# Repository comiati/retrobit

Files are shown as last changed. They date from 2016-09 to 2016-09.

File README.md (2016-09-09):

# RetroBit Game Console

This is a mix of retro game console with new technologies.

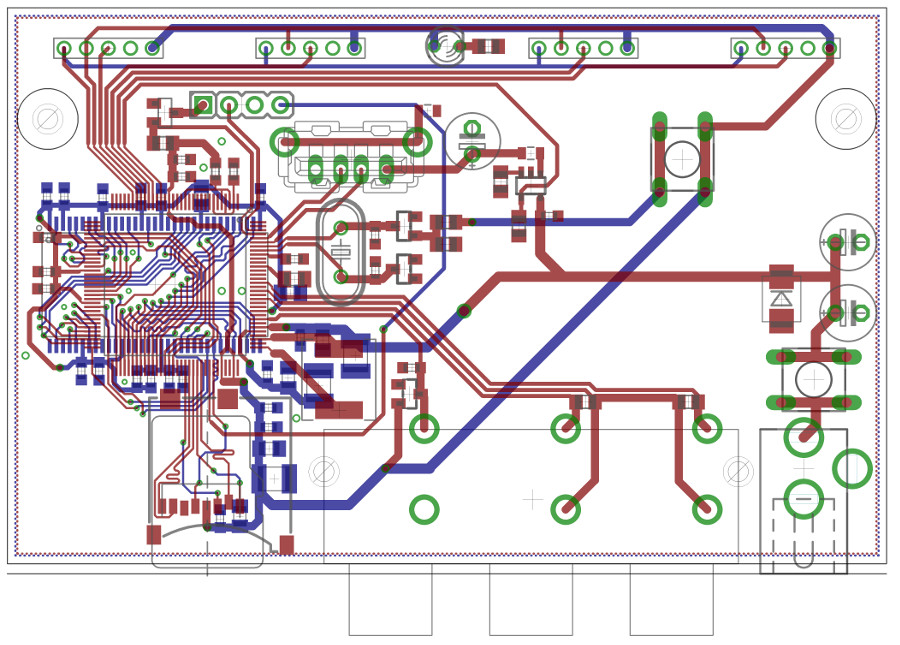
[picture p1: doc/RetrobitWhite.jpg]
RetroBit Board


## Hardware

This is ARM9 processor running at 454Mhz with enough power to run linux and still in handsolder friendly TQFP package, which allow hobby DIY approach. RetroBit is even on 2 layer PCB and running at full speed.

######

- i.MX233 128-QFP Processor ARM926EJ-S runs up to 454MHz
- Memory 64MB DDR SDRAM (32Mx16)
- One USB host.
- Four input game pad controls.
- One degub UART.
- Composite video output.
- Stereo sound output.
- Micro SD Card.
- Power suply with power button and Led.
- Reset button.

## Software

ArchLinux package for the moment is with most advanced Kernel and enabled features so this is our choice for the moment to build examples.

This hardware is based on OLinuxXino of www.olimex.com
https://github.com/OLIMEX/OLINUXINO/tree/master/SOFTWARE/iMX233

For more informations send email to: fabianotraple@gmail.com

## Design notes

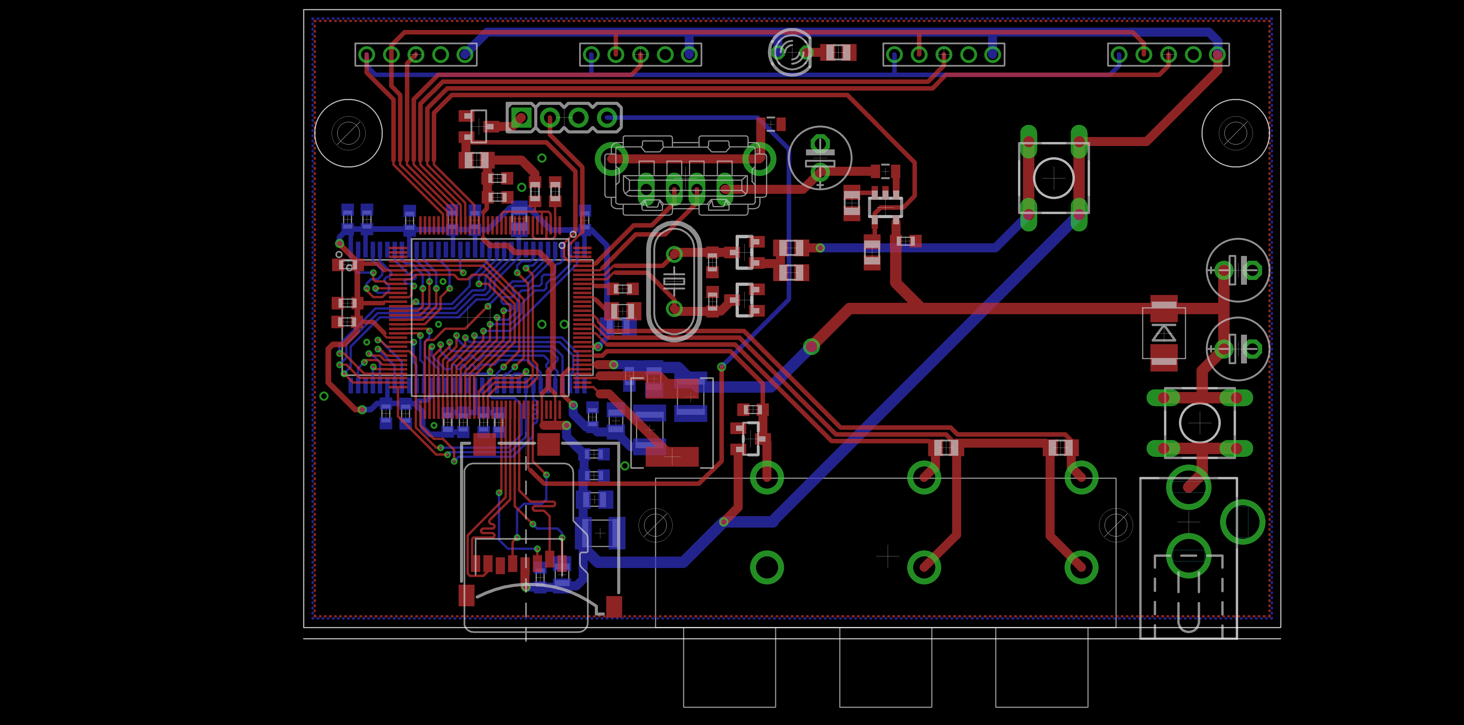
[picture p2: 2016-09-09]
doc/RetroBit.png

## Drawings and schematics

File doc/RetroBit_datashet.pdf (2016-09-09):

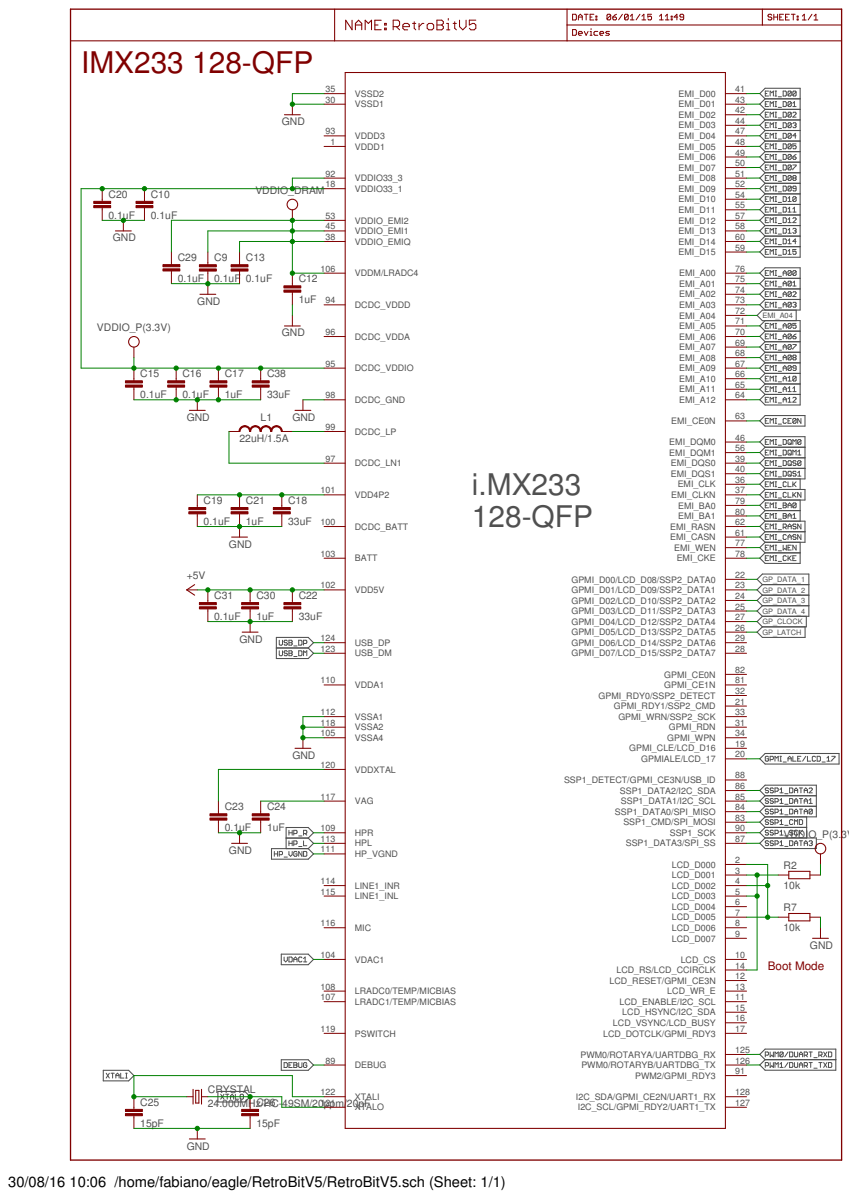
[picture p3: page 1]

4 | 10k R7

30/08/16 10:06 /home/fabiano/eagle/RetroBitV5/RetroBitV5.sch (Sheet: 1/1)

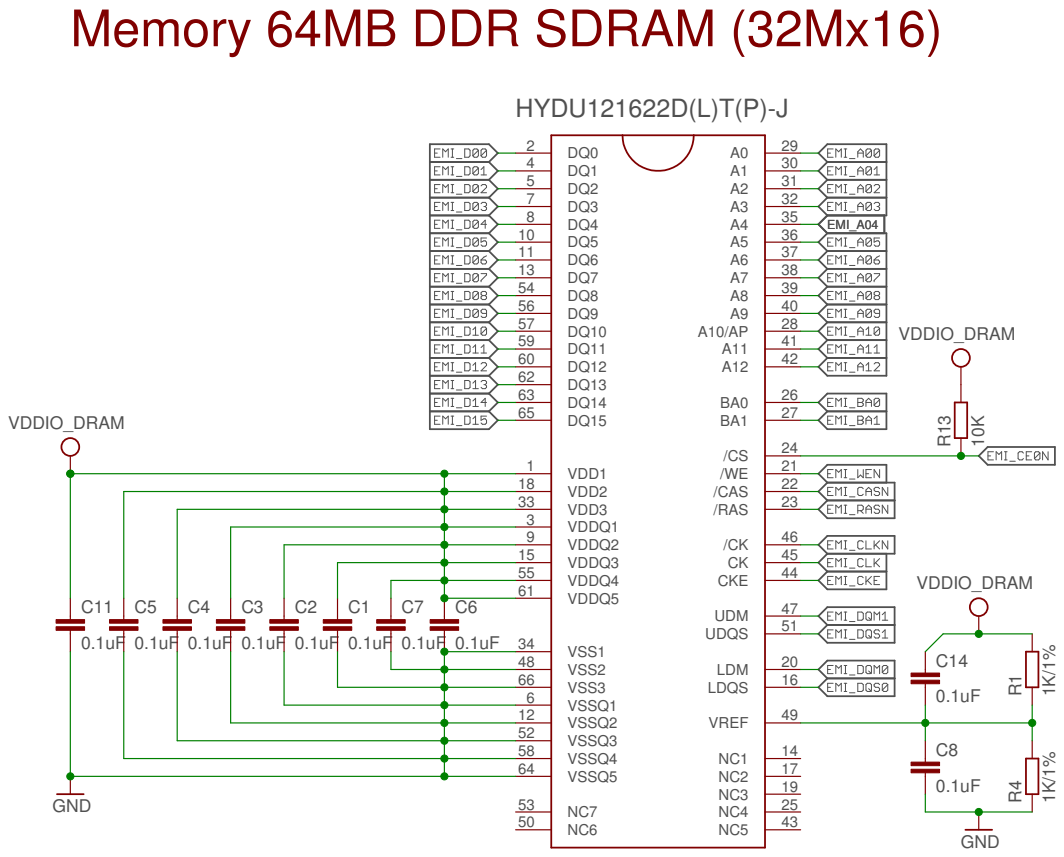
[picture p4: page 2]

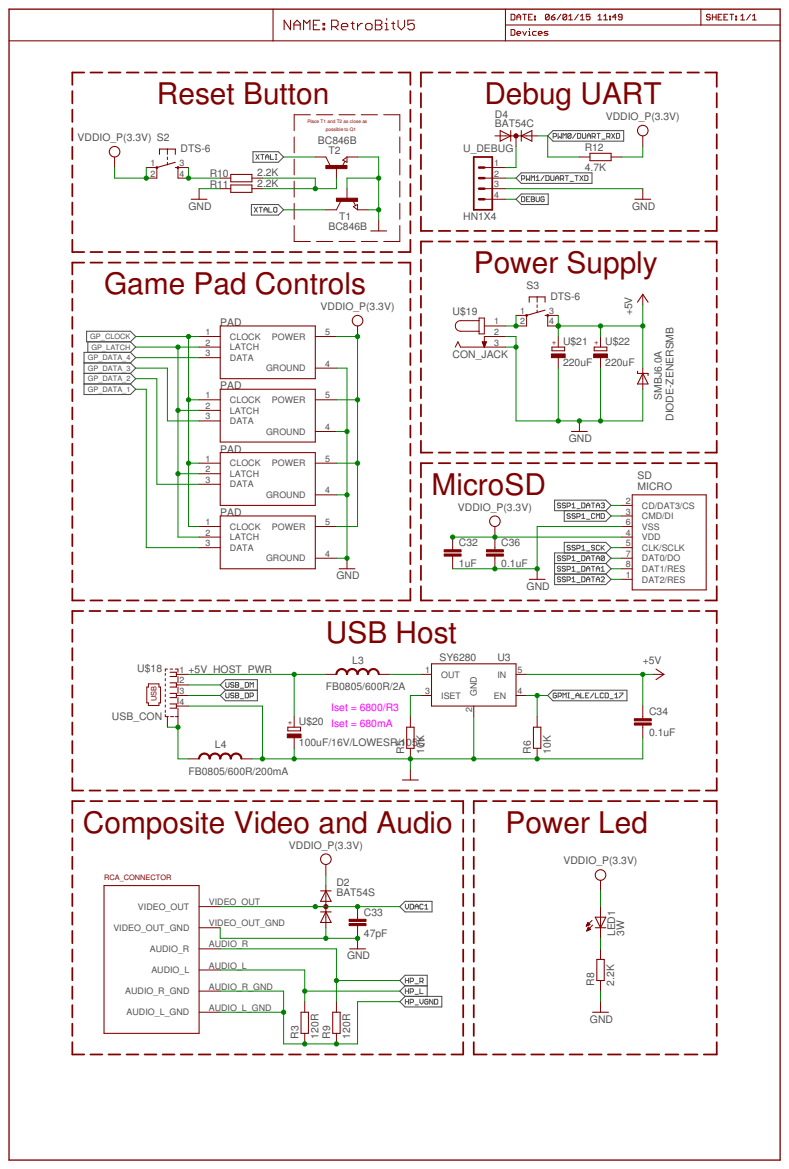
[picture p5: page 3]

Place T1 and T2 as close as possible to Q1 Reset Button

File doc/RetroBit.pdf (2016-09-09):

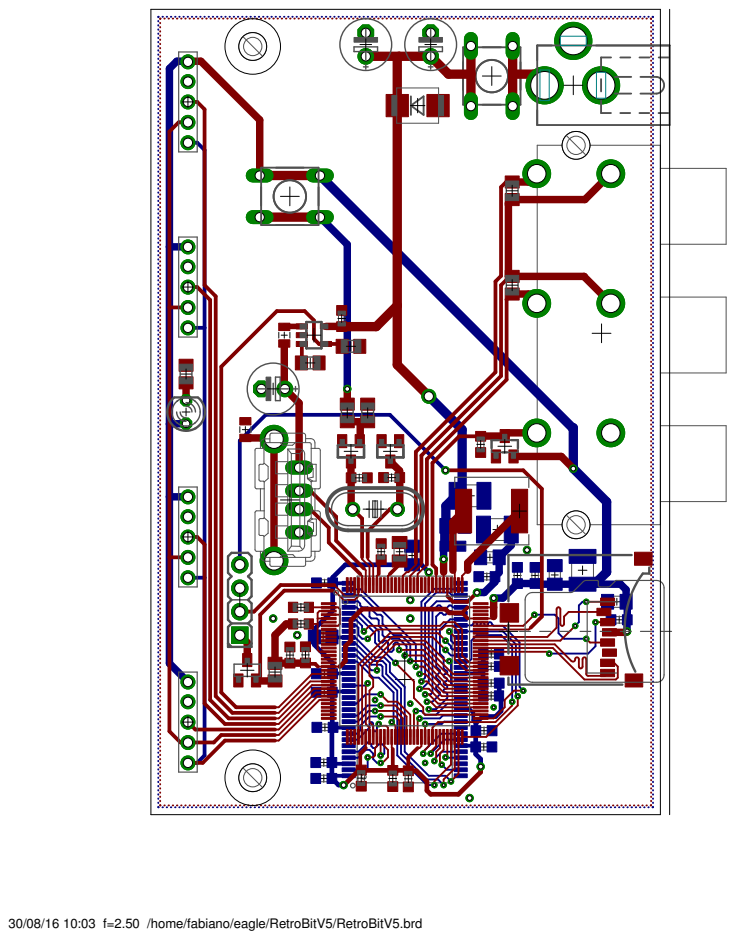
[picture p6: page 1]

30/08/16 10:03 f=2.50 /home/fabiano/eagle/RetroBitV5/RetroBitV5.brd

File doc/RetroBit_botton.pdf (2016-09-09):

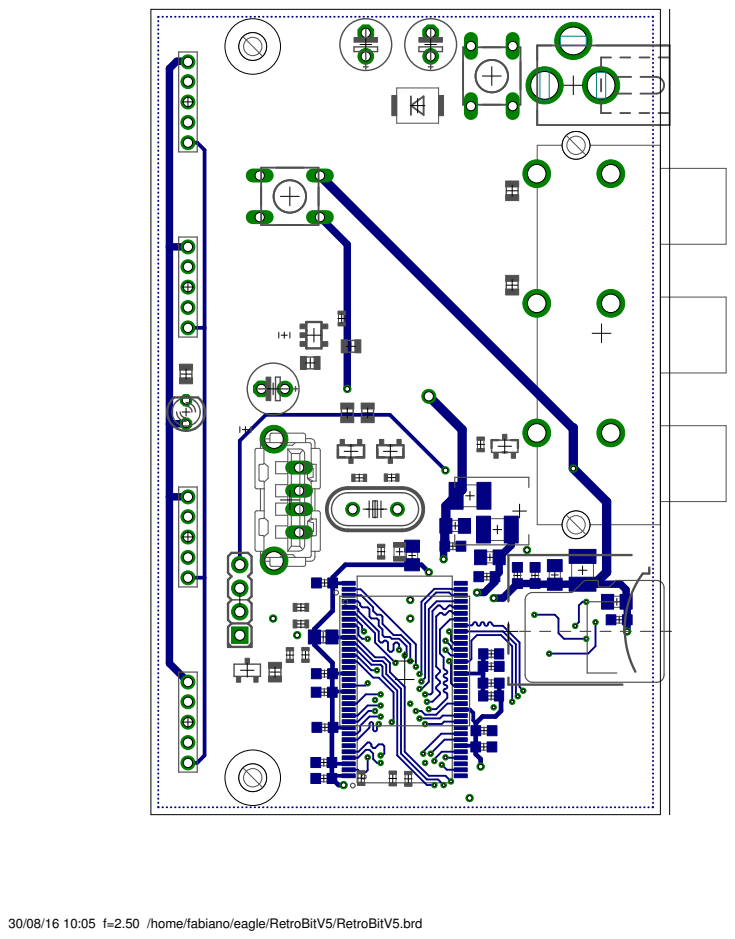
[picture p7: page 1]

30/08/16 10:05 f=2.50 /home/fabiano/eagle/RetroBitV5/RetroBitV5.brd

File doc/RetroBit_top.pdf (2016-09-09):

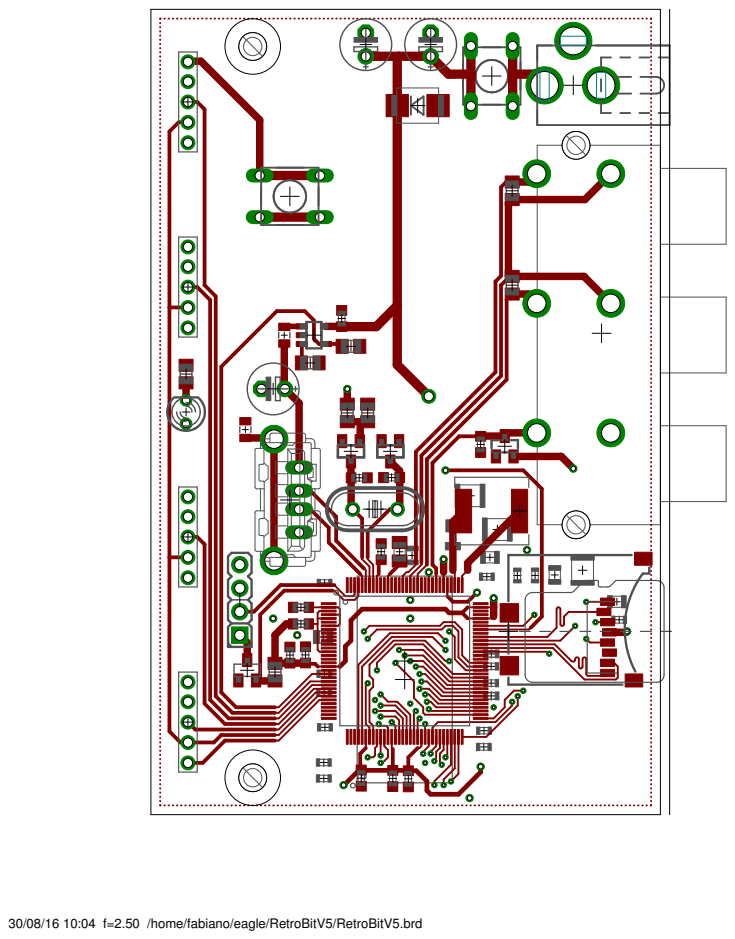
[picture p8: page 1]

30/08/16 10:04 f=2.50 /home/fabiano/eagle/RetroBitV5/RetroBitV5.brd

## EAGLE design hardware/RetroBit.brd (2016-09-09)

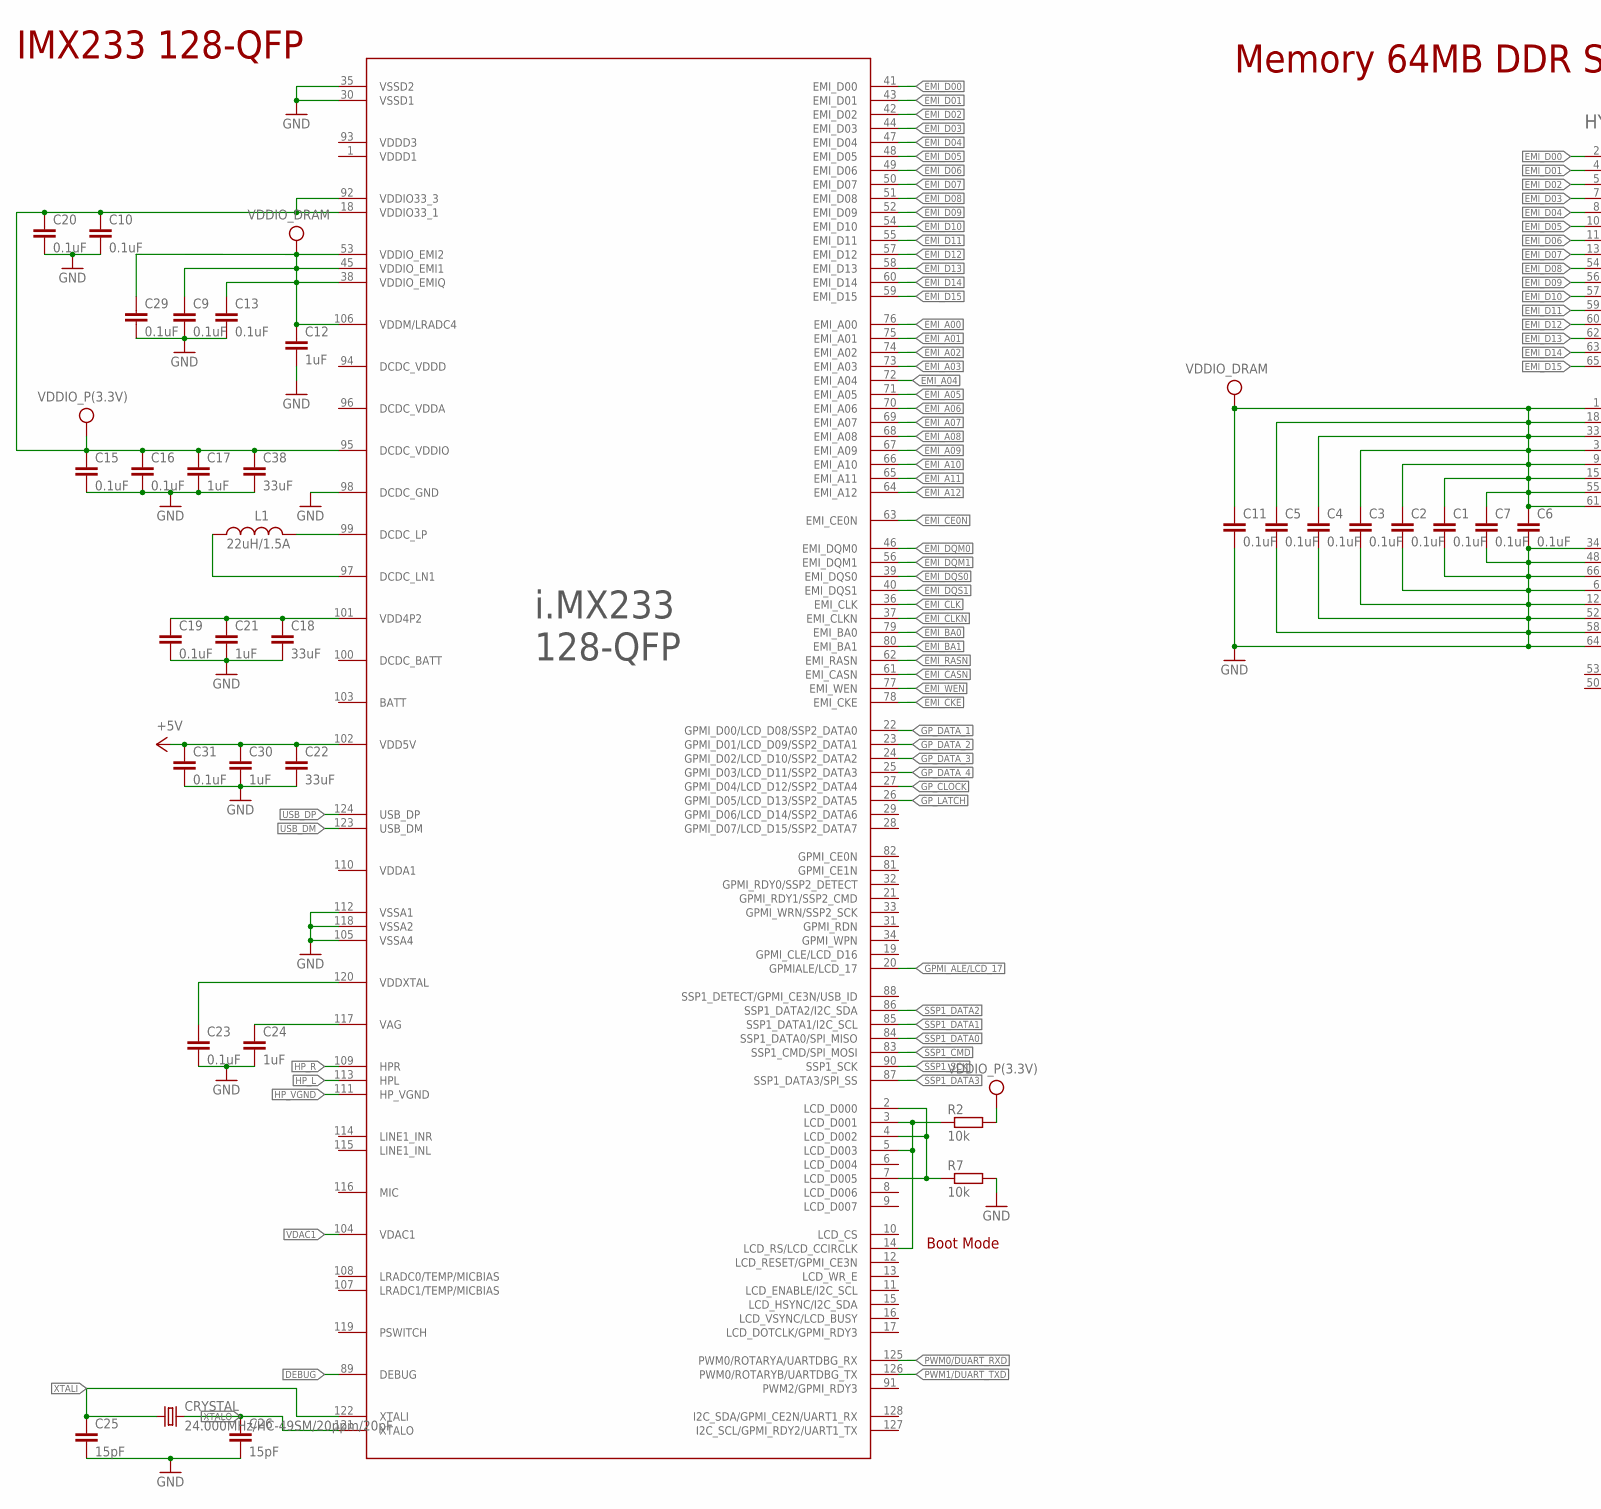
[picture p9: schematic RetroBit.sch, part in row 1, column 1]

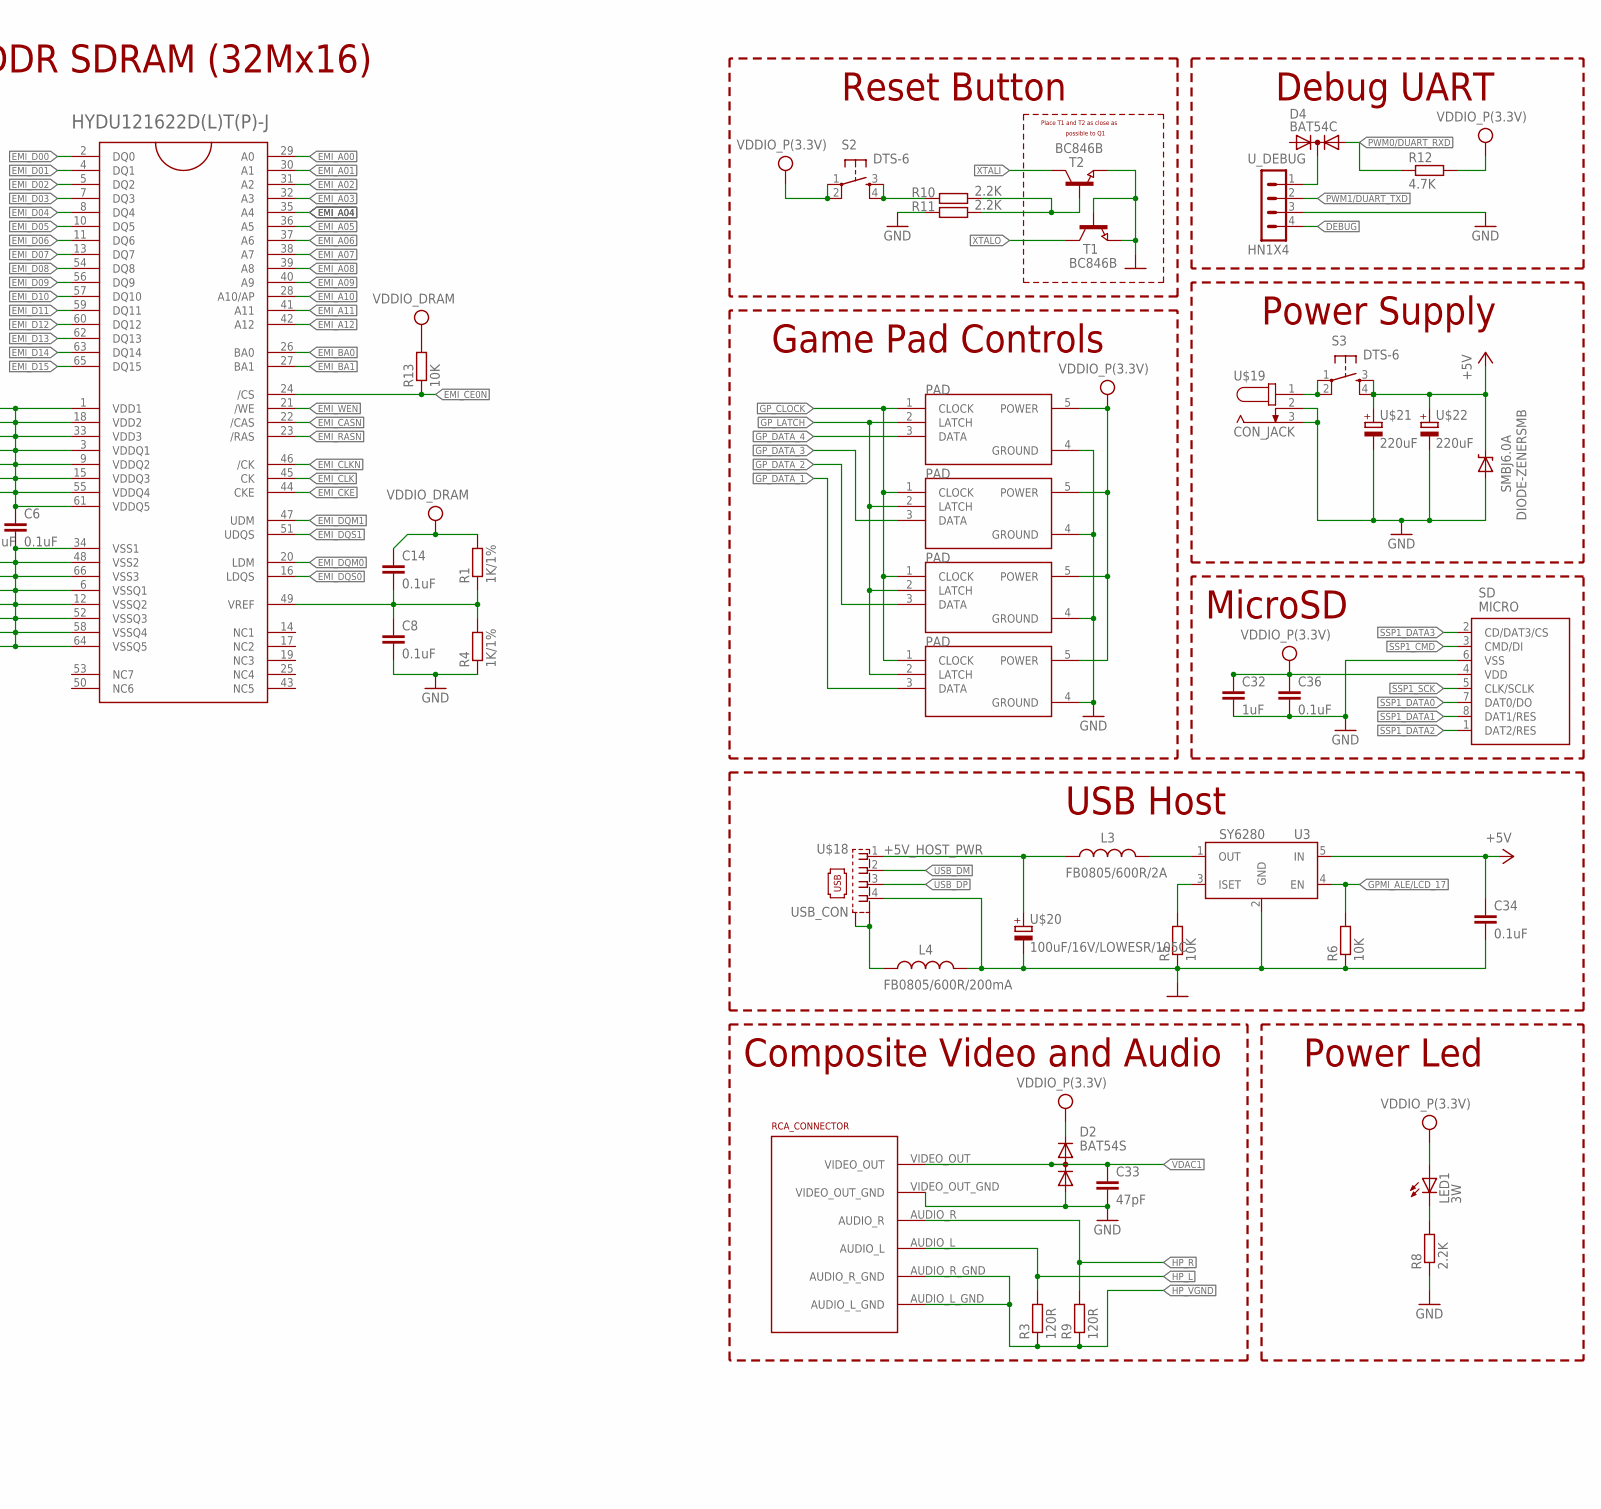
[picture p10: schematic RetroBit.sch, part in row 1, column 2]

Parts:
C1, C2, C3, C4, C5, C6, C7, C8, C9, C10, C11, C13, C14, C15, C16, C19, C20, C23, C29, C31, C34, C36: 0.1uF; C0603K
C12, C17, C21, C24, C30, C32: 1uF; C0805K
C18, C22, C38: 33uF; C1210K
C25, C26: 15pF; C0603K
C33: 47pF; C0603K
CRYSTAL: 24.000MHz/HC-49SM/20ppm/20pF; HC49U-V
D2: BAT54S; SOT23C(BAT54S)
D4: BAT54C; SOT23C
IC1: MCIMX233CAG4C
L1: 22uH/1.5A; CR75
L3: FB0805/600R/2A; 0805
L4: FB0805/600R/200mA; 0805
LED1: 3W; LED3MM
R1, R4: 1K/1%; R0603
R2, R7: 10k; R0603
R3, R9: 120R; R0805
R5, R6, R13: 10K; R0805
R8, R10, R11: 2.2K; R0805
R12: 4.7K; R0805
RCA_CONNECTOR: RCA_CONNECTOR
S2, S3: DTS-6
SD: MICRO; TFR-MEM-CON
SMBJ6.0A: DIODE-ZENERSMB; SMB-DIODE
T1, T2: BC846B; SOT23
U3: SY6280; SOT23-5
U$1: HY5DU121622D; HYDU121622D(L)T(P)-J
U$3, U$8, U$9, U$14: GAME_PAD
U$18: USB_CON
U$19: CON_JACK
U$20: 100uF/16V/LOWESR/105C; CPOL-EVE-2.5,6-3
U$21, U$22: 220uF; CPOL-EVE-2.5,6-3
U_DEBUG: HN1X4

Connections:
+5V: C22.1, C30.1, C31.1, C34.1, IC1.102 (VDD5V), S3.3, S3.4, SMBJ6.0A.C, U3.5 (IN), U$21.+, U$22.+
+5V_HOST_PWR: L3.1, U$18.1, U$20.+
DEBUG: IC1.89 (DEBUG), U_DEBUG.4
EMI_A00: IC1.76 (EMI_A00), U$1.29 (A0)
EMI_A01: IC1.75 (EMI_A01), U$1.30 (A1)
EMI_A02: IC1.74 (EMI_A02), U$1.31 (A2)
EMI_A03: IC1.73 (EMI_A03), U$1.32 (A3)
EMI_A04: IC1.72 (EMI_A04), U$1.35 (A4)
EMI_A05: IC1.71 (EMI_A05), U$1.36 (A5)
EMI_A06: IC1.70 (EMI_A06), U$1.37 (A6)
EMI_A07: IC1.69 (EMI_A07), U$1.38 (A7)
EMI_A08: IC1.68 (EMI_A08), U$1.39 (A8)
EMI_A09: IC1.67 (EMI_A09), U$1.40 (A9)
EMI_A10: IC1.66 (EMI_A10), U$1.28 (A10/AP)
EMI_A11: IC1.65 (EMI_A11), U$1.41 (A11)
EMI_A12: IC1.64 (EMI_A12), U$1.42 (A12)
EMI_BA0: IC1.79 (EMI_BA0), U$1.26 (BA0)
EMI_BA1: IC1.80 (EMI_BA1), U$1.27 (BA1)
EMI_CASN: IC1.61 (EMI_CASN), U$1.22 (/CAS)
EMI_CE0N: IC1.63 (EMI_CE0N), R13.1, U$1.24 (/CS)
EMI_CKE: IC1.78 (EMI_CKE), U$1.44 (CKE)
EMI_CLK: IC1.36 (EMI_CLK), U$1.45 (CK)
EMI_CLKN: IC1.37 (EMI_CLKN), U$1.46 (/CK)
EMI_D00: IC1.41 (EMI_D00), U$1.2 (DQ0)
EMI_D01: IC1.43 (EMI_D01), U$1.4 (DQ1)
EMI_D02: IC1.42 (EMI_D02), U$1.5 (DQ2)
EMI_D03: IC1.44 (EMI_D03), U$1.7 (DQ3)
EMI_D04: IC1.47 (EMI_D04), U$1.8 (DQ4)
EMI_D05: IC1.48 (EMI_D05), U$1.10 (DQ5)
EMI_D06: IC1.49 (EMI_D06), U$1.11 (DQ6)
EMI_D07: IC1.50 (EMI_D07), U$1.13 (DQ7)
EMI_D08: IC1.51 (EMI_D08), U$1.54 (DQ8)
EMI_D09: IC1.52 (EMI_D09), U$1.56 (DQ9)
EMI_D10: IC1.54 (EMI_D10), U$1.57 (DQ10)
EMI_D11: IC1.55 (EMI_D11), U$1.59 (DQ11)
EMI_D12: IC1.57 (EMI_D12), U$1.60 (DQ12)
EMI_D13: IC1.58 (EMI_D13), U$1.62 (DQ13)
EMI_D14: IC1.60 (EMI_D14), U$1.63 (DQ14)
EMI_D15: IC1.59 (EMI_D15), U$1.65 (DQ15)
EMI_DQM0: IC1.46 (EMI_DQM0), U$1.20 (LDM)
EMI_DQM1: IC1.56 (EMI_DQM1), U$1.47 (UDM)
EMI_DQS0: IC1.39 (EMI_DQS0), U$1.16 (LDQS)
EMI_DQS1: IC1.40 (EMI_DQS1), U$1.51 (UDQS)
EMI_RASN: IC1.62 (EMI_RASN), U$1.23 (/RAS)
EMI_WEN: IC1.77 (EMI_WEN), U$1.21 (/WE)
GND: C1.2, C2.2, C3.2, C4.2, C5.2, C6.2, C7.2, C8.2, C9.2, C10.2, C11.2, C12.2, C13.2, C15.2, C16.2, C17.2, C18.2, C19.2, C20.2, C21.2, C22.2, C23.2, C24.2, C25.2, C26.2, C29.2, C30.2, C31.2, C32.2, C33.2, C34.2, C36.2, C38.2, D2.1 (A), IC1.30 (VSSD1), IC1.35 (VSSD2), IC1.98 (DCDC_GND), IC1.105 (VSSA4), IC1.112 (VSSA1), IC1.118 (VSSA2), L4.2, R4.1, R5.1, R6.1, R7.2, R8.1, R11.1, RCA_CONNECTOR.VIDEO_OUT_GND, SD.6 (VSS), SMBJ6.0A.A, T1.1 (B), T1.2 (E), T2.2 (E), U3.2 (GND), U$1.6 (VSSQ1), U$1.12 (VSSQ2), U$1.34 (VSS1), U$1.48 (VSS2), U$1.52 (VSSQ3), U$1.58 (VSSQ4), U$1.64 (VSSQ5), U$1.66 (VSS3), U$3.4 (GROUND), U$8.4 (GROUND), U$9.4 (GROUND), U$14.4 (GROUND), U$18.4, U$19.2, U$19.3 (1), U$20.-, U$21.-, U$22.-, U_DEBUG.3
GPMI_ALE/LCD_17: IC1.20 (GPMIALE/LCD_17), R6.2, U3.4 (EN)
GP_CLOCK: IC1.27 (GPMI_D04/LCD_D12/SSP2_DATA4), U$3.1 (CLOCK), U$8.1 (CLOCK), U$9.1 (CLOCK), U$14.1 (CLOCK)
GP_DATA_1: IC1.22 (GPMI_D00/LCD_D08/SSP2_DATA0), U$14.3 (DATA)
GP_DATA_2: IC1.23 (GPMI_D01/LCD_D09/SSP2_DATA1), U$9.3 (DATA)
GP_DATA_3: IC1.24 (GPMI_D02/LCD_D10/SSP2_DATA2), U$8.3 (DATA)
GP_DATA_4: IC1.25 (GPMI_D03/LCD_D11/SSP2_DATA3), U$3.3 (DATA)
GP_LATCH: IC1.26 (GPMI_D05/LCD_D13/SSP2_DATA5), U$3.2 (LATCH), U$8.2 (LATCH), U$9.2 (LATCH), U$14.2 (LATCH)
HP_L: IC1.113 (HPL), R3.2, RCA_CONNECTOR.AUDIO_L
HP_R: IC1.109 (HPR), R9.2, RCA_CONNECTOR.AUDIO_R
HP_VGND: IC1.111 (HP_VGND), R3.1, R9.1, RCA_CONNECTOR.AUDIO_L_GND, RCA_CONNECTOR.AUDIO_R_GND
unnamed: D4.3 (K), U_DEBUG.1
unnamed: C8.1, C14.2, R1.1, R4.2, U$1.49 (VREF)
unnamed: S3.1, S3.2, U$19.1 (3)
unnamed: C18.1, C19.1, C21.1, IC1.101 (VDD4P2)
unnamed: IC1.99 (DCDC_LP), L1.P$2 (2)
unnamed: IC1.3 (LCD_D001), IC1.5 (LCD_D003), IC1.14 (LCD_RS/LCD_CCIRCLK), R2.1
unnamed: IC1.97 (DCDC_LN1), L1.P$1 (1)
unnamed: R5.2, U3.3 (ISET)
unnamed: C23.1, IC1.120 (VDDXTAL)
unnamed: L3.2, U3.1 (OUT)
unnamed: L4.1, U$18.M1 (S1), U$18.M2 (S2)
unnamed: C24.1, IC1.117 (VAG)
unnamed: IC1.2 (LCD_D000), IC1.4 (LCD_D002), IC1.7 (LCD_D005), R7.1
unnamed: LED1.K (C), R8.2
unnamed: R10.1, S2.3, S2.4
unnamed: R10.2, R11.2, T2.1 (B)
PWM0/DUART_RXD: D4.2 (A2), IC1.125 (PWM0/ROTARYA/UARTDBG_RX), R12.1
PWM1/DUART_TXD: IC1.126 (PWM0/ROTARYB/UARTDBG_TX), U_DEBUG.2
SSP1_CMD: IC1.83 (SSP1_CMD/SPI_MOSI), SD.3 (CMD/DI)
SSP1_DATA0: IC1.84 (SSP1_DATA0/SPI_MISO), SD.7 (DAT0/DO)
SSP1_DATA1: IC1.85 (SSP1_DATA1/I2C_SCL), SD.8 (DAT1/RES)
SSP1_DATA2: IC1.86 (SSP1_DATA2/I2C_SDA), SD.1 (DAT2/RES)
SSP1_DATA3: IC1.87 (SSP1_DATA3/SPI_SS), SD.2 (CD/DAT3/CS)
SSP1_SCK: IC1.90 (SSP1_SCK), SD.5 (CLK/SCLK)
USB_DM: IC1.123 (USB_DM), U$18.2
USB_DP: IC1.124 (USB_DP), U$18.3
VDAC1: C33.1, D2.3 (AK), IC1.104 (VDAC1), RCA_CONNECTOR.VIDEO_OUT
VDDIO_DRAM: C1.1, C2.1, C3.1, C4.1, C5.1, C6.1, C7.1, C9.1, C11.1, C12.1, C13.1, C14.1, C29.1, IC1.38 (VDDIO_EMIQ), IC1.45 (VDDIO_EMI1), IC1.53 (VDDIO_EMI2), IC1.106 (VDDM/LRADC4), R1.2, R13.2, U$1.1 (VDD1), U$1.3 (VDDQ1), U$1.9 (VDDQ2), U$1.15 (VDDQ3), U$1.18 (VDD2), U$1.33 (VDD3), U$1.55 (VDDQ4), U$1.61 (VDDQ5)
VDDIO_P(3.3V): C10.1, C15.1, C16.1, C17.1, C20.1, C32.1, C36.1, C38.1, D2.2 (K), IC1.18 (VDDIO33_1), IC1.92 (VDDIO33_3), IC1.95 (DCDC_VDDIO), LED1.A, R2.2, R12.2, S2.1, S2.2, SD.4 (VDD), U$3.5 (POWER), U$8.5 (POWER), U$9.5 (POWER), U$14.5 (POWER)
XTALI: C25.1, CRYSTAL.1, IC1.122 (XTALI), T2.3 (C)
XTALO: C26.1, CRYSTAL.2, IC1.121 (XTALO), T1.3 (C)

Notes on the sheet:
MicroSD
Place T1 and T2 as close as
possible to Q1
Reset Button
Boot Mode
Game Pad Controls
Memory 64MB DDR SDRAM (32Mx16)
Power Supply
USB Host
Composite Video and Audio
Power Led
Debug UART
IMX233 128-QFP

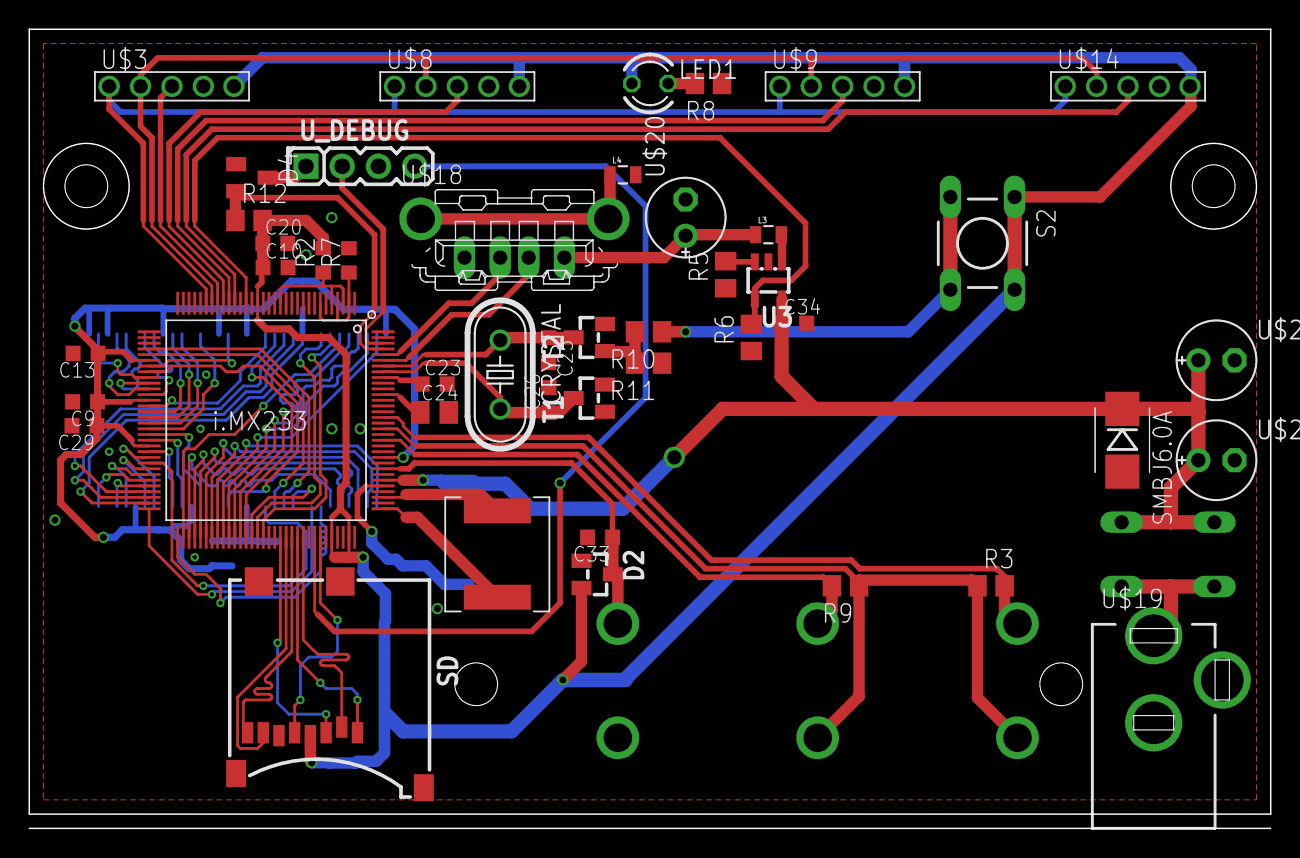
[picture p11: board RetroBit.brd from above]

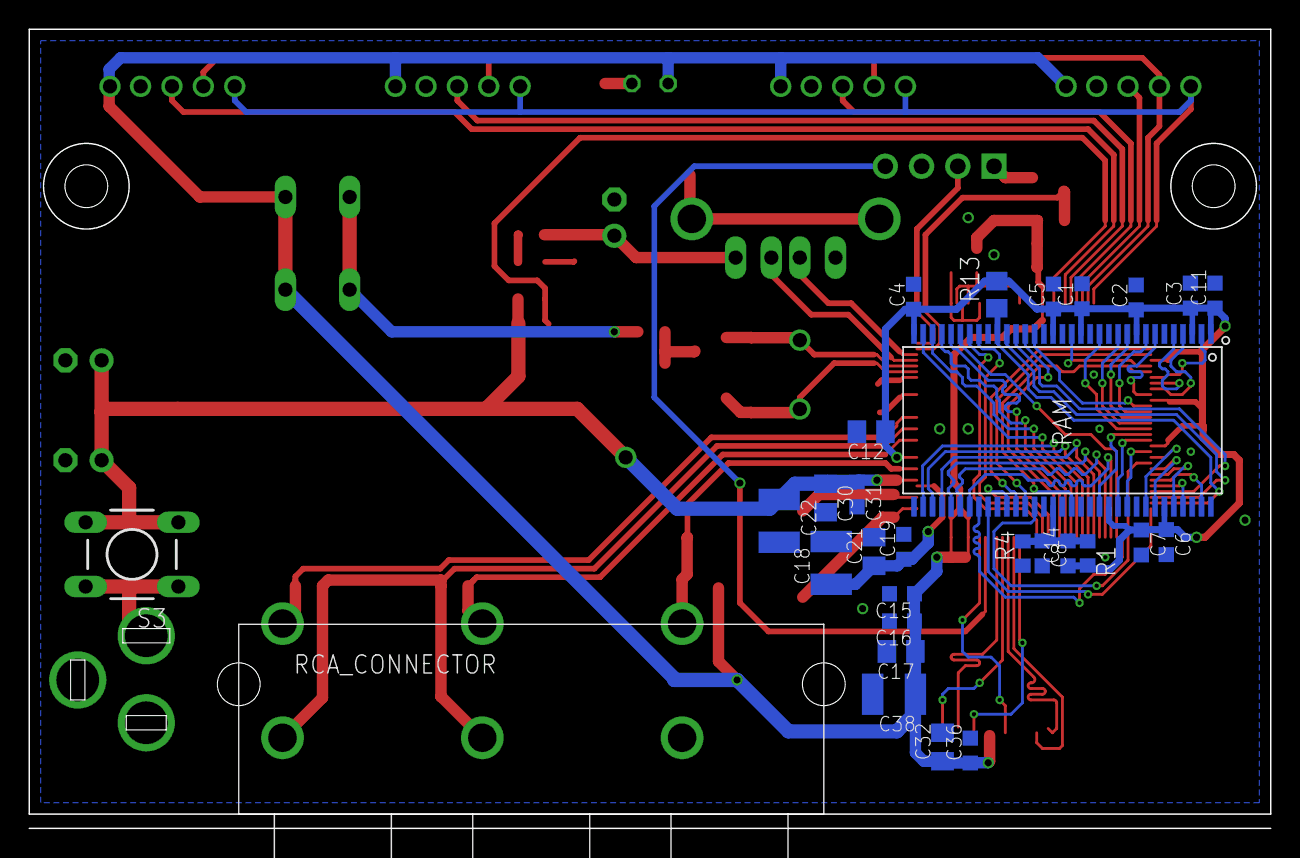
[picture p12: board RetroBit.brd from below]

Board: 2 copper layers, 87.0 x 56.0 mm, 74 parts (29 on the bottom side), 87 nets.

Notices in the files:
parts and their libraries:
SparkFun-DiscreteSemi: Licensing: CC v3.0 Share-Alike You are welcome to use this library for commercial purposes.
